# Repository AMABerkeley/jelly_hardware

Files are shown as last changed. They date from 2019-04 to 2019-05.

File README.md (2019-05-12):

# jelly_hardware
Hardware for Jelly Robot

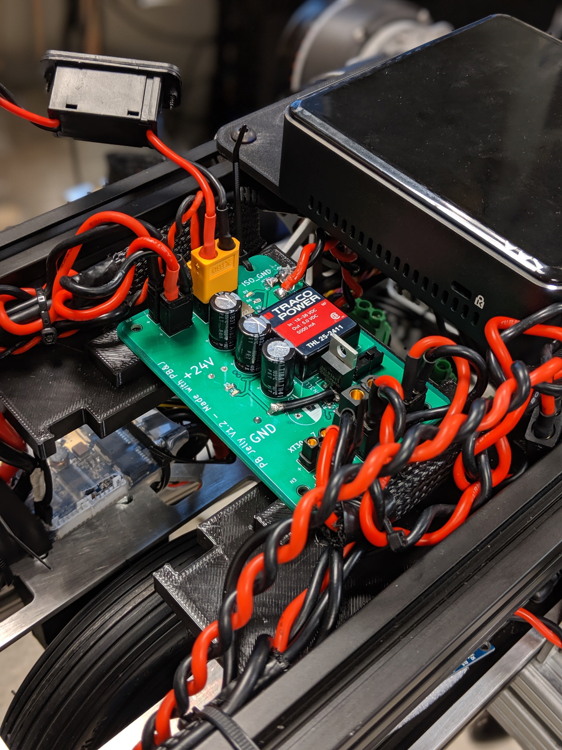
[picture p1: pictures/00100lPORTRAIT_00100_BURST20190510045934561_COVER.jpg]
3dview


More to come...

Useful for protecting against sparks and having an isolated ground for a computer.

Input Voltage is 24V from this device: [Kobalt](https://www.lowes.com/pd/Kobalt-24-Volt-1-5-Amp-Hours-Lithium-Power-Tool-Battery/1000090833)

Output Voltage at XT30 and XT60 is 24V

Output Voltage at Isolated pins: 5V 5A

V1.0 has been sent out.

TODO V2.0: Add PMOS to 24V to prevent damage to circuit if battery connected wrong way. Add connector for computer power. Add LED indicators.

Components:

DCDC Isolated 5V5A
https://www.digikey.com/product-detail/en/traco-power/THL-25-2411/1951-1620-ND/9382657
https://www.tracopower.com/products/thl25.pdf
https://assets.tracopower.com/20190412132953/THL25/documents/thl25-application.pdf

Inductor
https://www.mouser.com/ProductDetail/Coilcraft/XEL6060-222MEB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

NMOS
current nmos https://www.digikey.com/product-detail/en/stmicroelectronics/STP160N3LL/497-16021-5-ND/5455754
backup NMOS https://www.digikey.com/product-detail/en/infineon-technologies/IRLB3813PBF/IRLB3813PBF-ND/2118485

Batttery Terminal Connector
https://www.digikey.com/product-detail/en/te-connectivity-amp-connectors/1-725996-2/A130982-ND/2055902
Specs https://www.te.com/commerce/DocumentDelivery/DDEController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

Inspiration: https://easyeda.com/editor#id=83191bc7c7a1436bab31f7c8314d08c5|0a66ceef99064df6ad66a18129efbc26

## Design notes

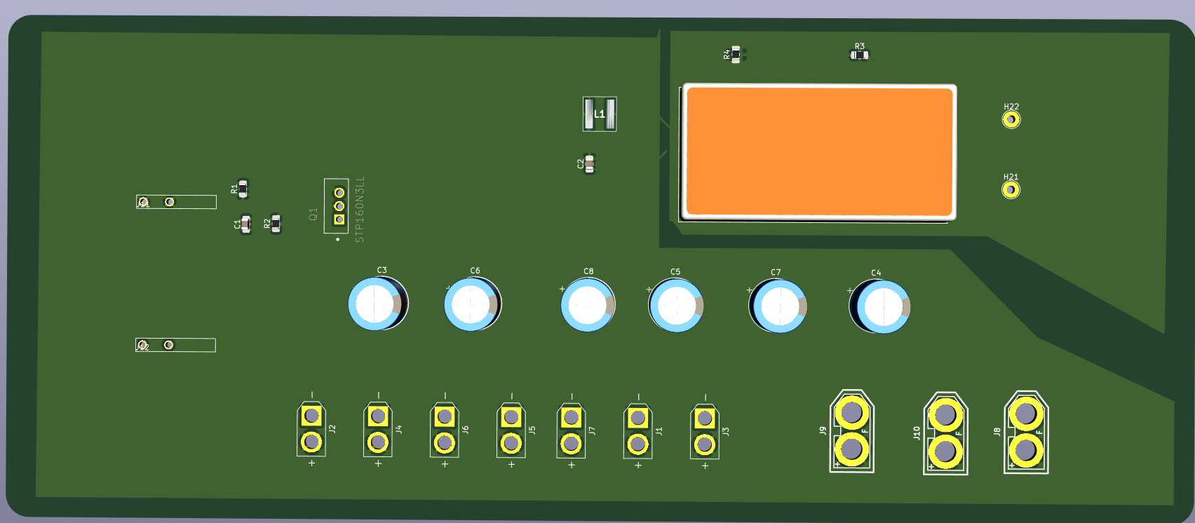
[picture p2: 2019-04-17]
pictures/3dview.png

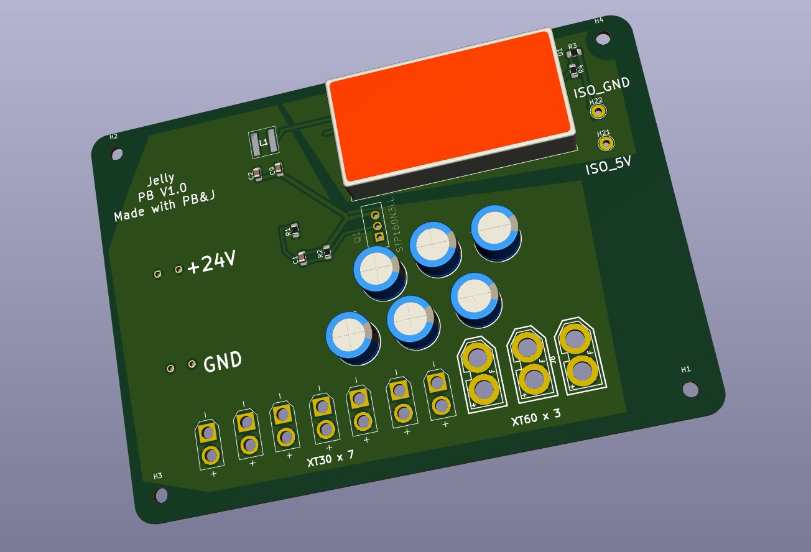
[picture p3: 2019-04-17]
pictures/05C11D99-9A95-4C3E-8D60-CFA752C3F91C.jpeg

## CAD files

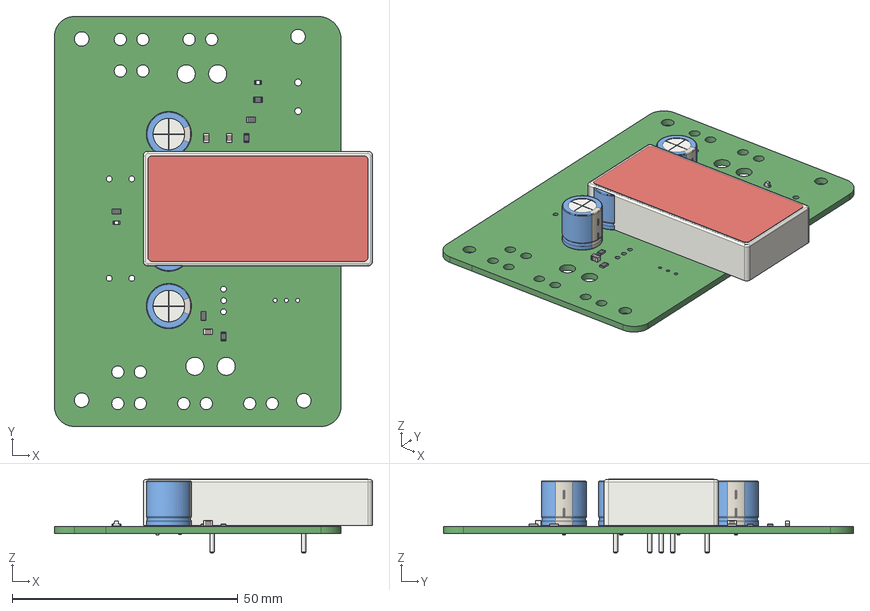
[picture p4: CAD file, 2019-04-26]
power board.step
70.5 x 90.8 x 16.3 mm

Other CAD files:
kicad-footprints-master/Sources/Inductor_SMD/L_Coilcraft_LPS5030.FCStd
kicad-footprints-master/Sources/Package_SON/X2SON-4_1x1mm_P0.65mm.fcstd
kicad-footprints-master/Sources/Package_TO_SOT_THT/sod-70_P5.08mm.fcstd
kicad-footprints-master/Sources/Package_TO_SOT_THT/sod-70.fcstd

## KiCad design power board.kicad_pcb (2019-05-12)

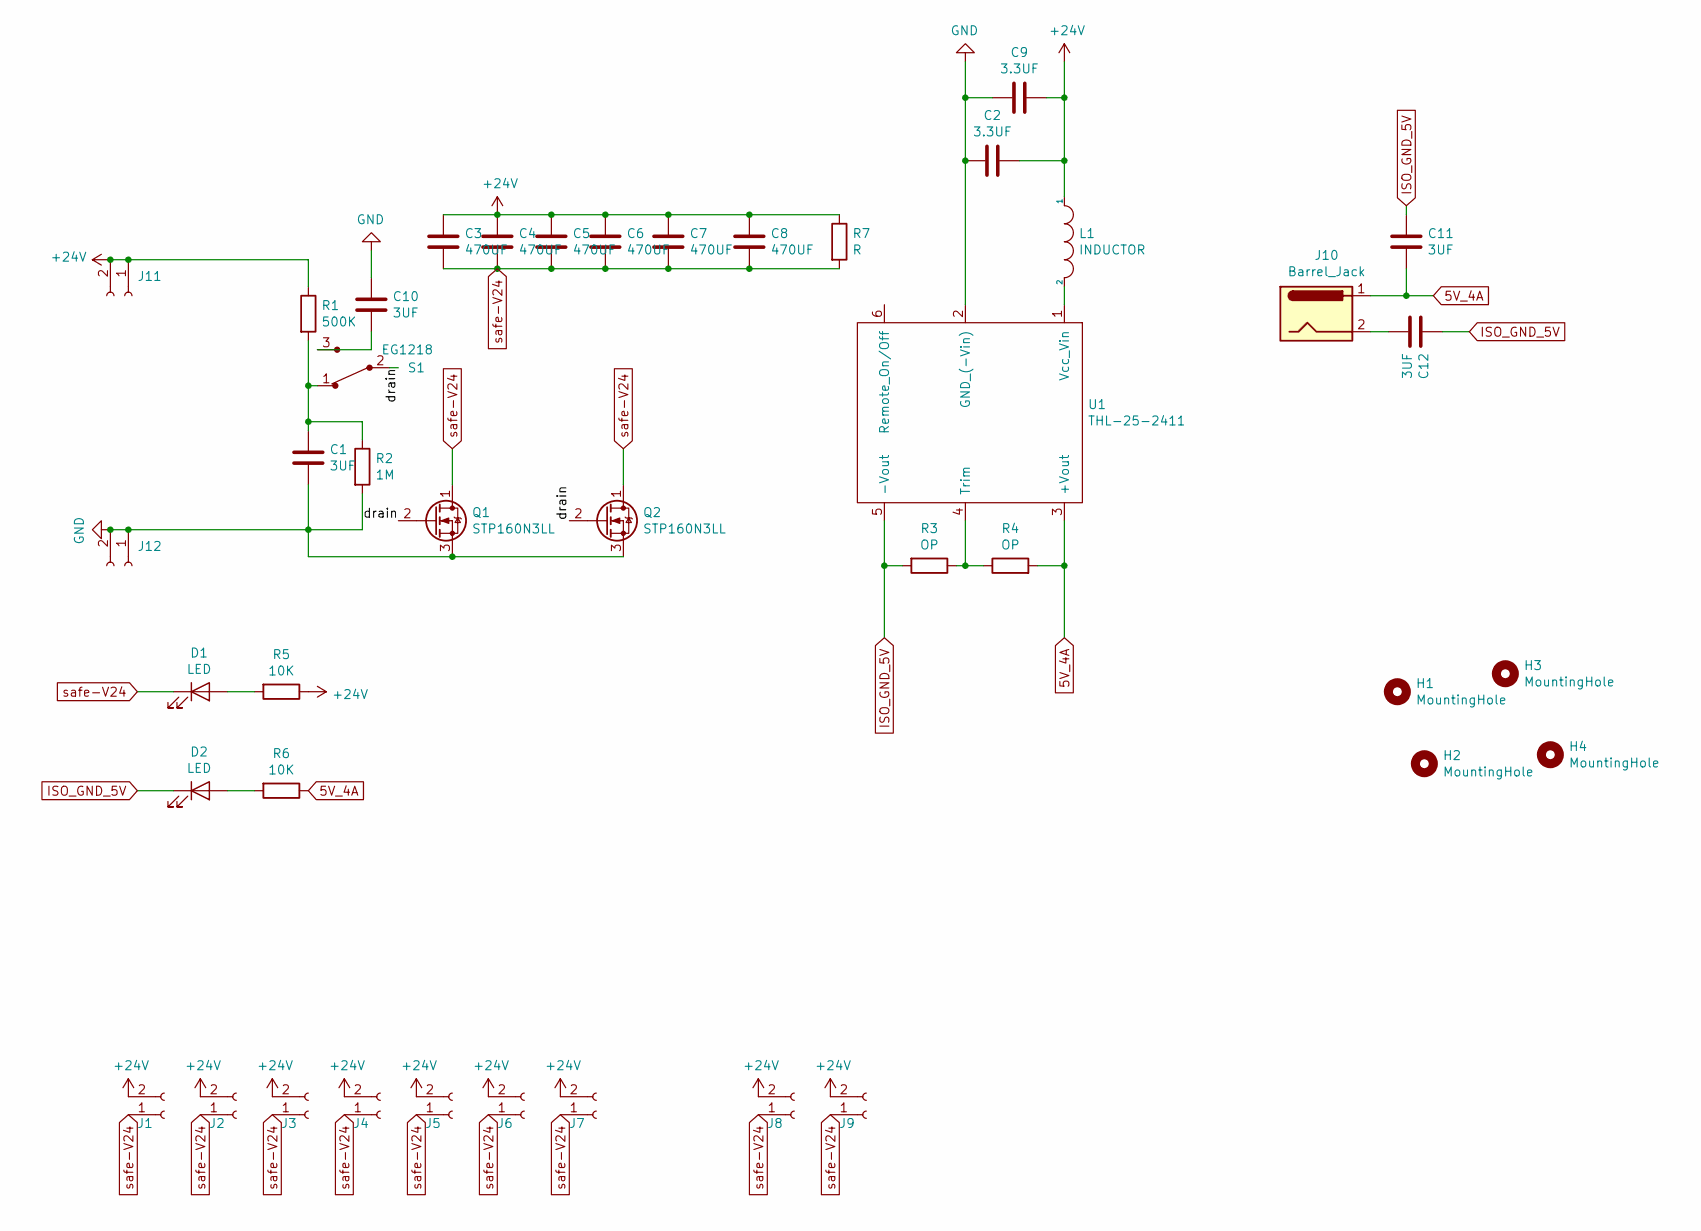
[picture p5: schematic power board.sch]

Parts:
C1, C10, C11, C12: 3UF; C_0805_2012Metric_Pad1.15x1.40mm_HandSolder
C2, C9: 3.3UF; C_0805_2012Metric_Pad1.15x1.40mm_HandSolder
C3, C4, C5, C6, C7, C8: 470UF; CP_Radial_D10.0mm_P5.00mm
D1, D2: LED; LED_0603_1608Metric_Pad1.05x0.95mm_HandSolder
H1, H2, H3, H4: MountingHole; MountingHole_3.2mm_M3_Pad_Via
J1, J2, J3, J4, J5, J6, J7: Conn_01x02_Female; AMASS_XT30U-F_1x02_P5.0mm_Vertical
J8, J9: Conn_01x02_Female; XT-60_female
J10: Barrel_Jack; BarrelJack_CUI_PJ-063AH_Horizontal
J11, J12: Conn_01x02_Female; battery_conector_powerpack
L1: INDUCTOR; XEL6060-152MEC
Q1, Q2: STP160N3LL; MOSFET_Down
R1: 500K; R_0805_2012Metric_Pad1.15x1.40mm_HandSolder
R2: 1M; R_0805_2012Metric_Pad1.15x1.40mm_HandSolder
R3, R4: OP; R_0805_2012Metric_Pad1.15x1.40mm_HandSolder
R5, R6: 10K; R_0805_2012Metric_Pad1.15x1.40mm_HandSolder
R7: R; R_0805_2012Metric_Pad1.15x1.40mm_HandSolder
S1: EG1218; Switch_Slide_11.6x4mm_EG1218; MPN EG1218; Digi-Key_PN EG1903-ND
U1: THL-25-2411; Converter_DCDC_TRACO_TEN20-xxxx_THT-modified

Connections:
5V_4A: C11.2, J10.1, R4.2, R6.1, U1.3 (+Vout)
+24V: C2.2, C3.1, C4.1, C5.1, C6.1, C7.1, C8.1, C9.2, J1.2, J2.2, J3.2, J4.2, J5.2, J6.2, J7.2, J8.2, J9.2, J11.1, J11.2, L1.1, R1.1, R5.1, R7.1
/drain: Q1.2 (G), Q2.2 (G), S1.2
GND: C1.2, C2.1, C9.1, C10.1, J12.1, J12.2, Q1.3 (S), Q2.3 (S), R2.2, U1.2 (GND_(-Vin))
ISO_GND_5V: C11.1, C12.1, D2.1 (K), R3.2, U1.5 (-Vout)
unnamed: C1.1, R1.2, R2.1, S1.1
unnamed: C10.2, S1.3
unnamed: C12.2, J10.2
unnamed: D1.2 (A), R5.2
unnamed: D2.2 (A), R6.2
unnamed: L1.2, U1.1 (Vcc_Vin)
unnamed: R3.1, R4.1, U1.4 (Trim)
safe-V24: C3.2, C4.2, C5.2, C6.2, C7.2, C8.2, D1.1 (K), J1.1, J2.1, J3.1, J4.1, J5.1, J6.1, J7.1, J8.1, J9.1, Q1.1 (D), Q2.1 (D), R7.2

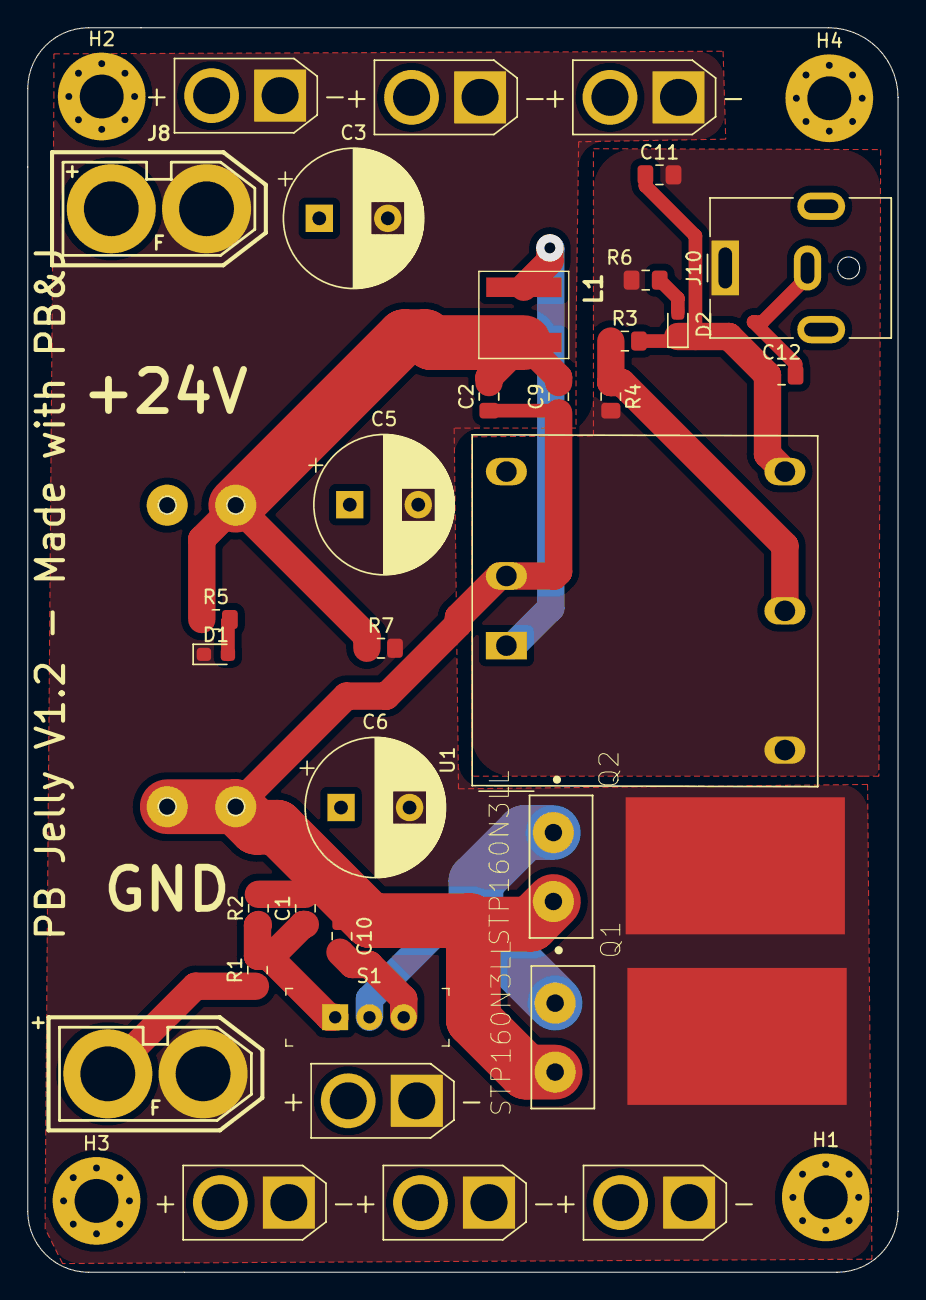
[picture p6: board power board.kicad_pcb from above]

Board: 2 copper layers, 63.5 x 90.8 mm, 39 parts (0 on the bottom side), 13 nets.

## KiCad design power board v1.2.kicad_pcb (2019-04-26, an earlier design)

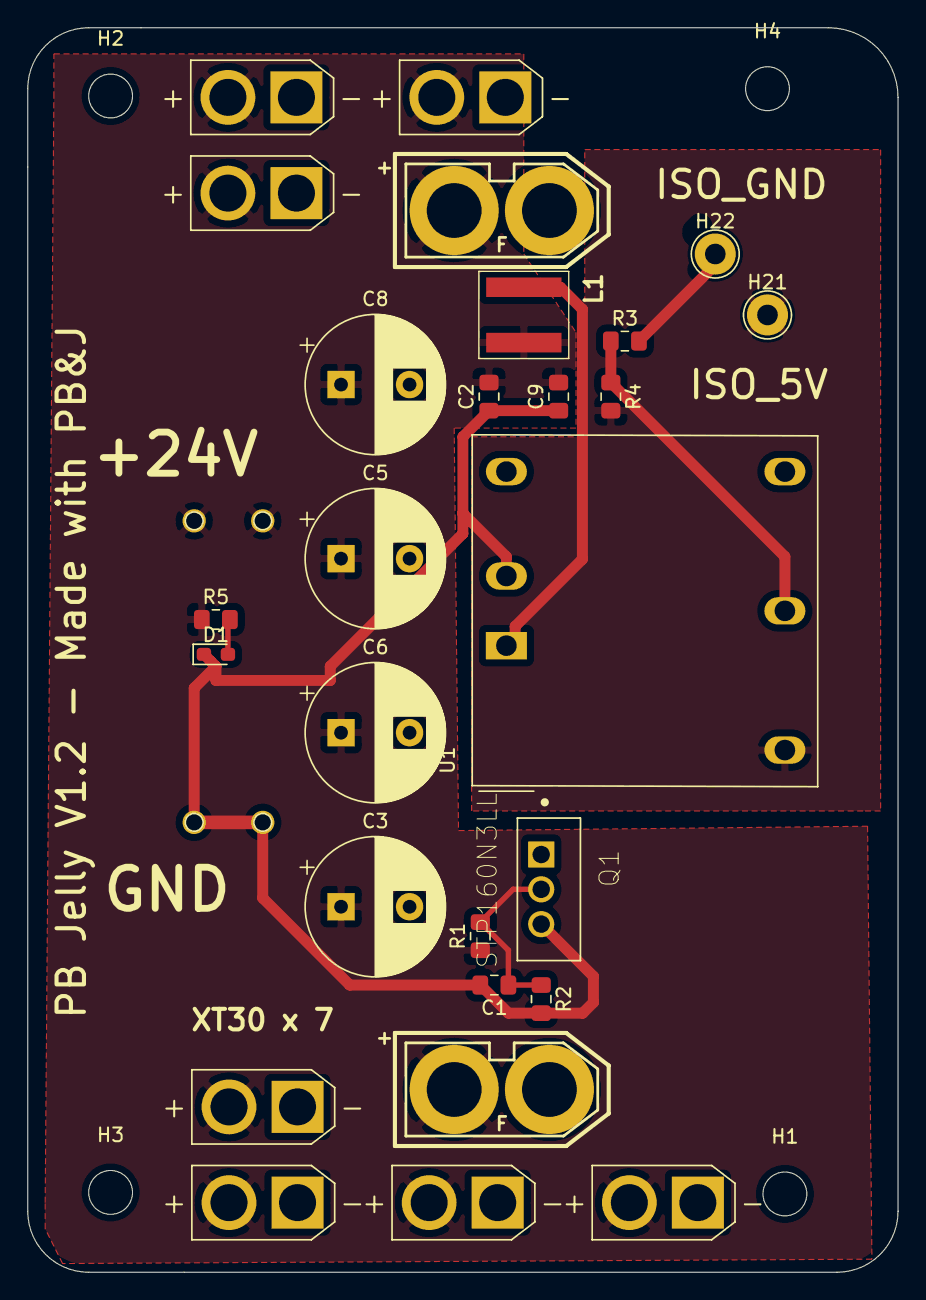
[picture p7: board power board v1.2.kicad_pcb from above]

Board: 2 copper layers, 63.5 x 90.8 mm, 33 parts (0 on the bottom side), 9 nets.

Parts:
C1: .1UF; C_0805_2012Metric_Pad1.15x1.40mm_HandSolder
C2, C9: 3.3UF; C_0805_2012Metric_Pad1.15x1.40mm_HandSolder
C3, C5, C6, C8: 470UF; CP_Radial_D10.0mm_P5.00mm
D1: LED; LED_0603_1608Metric_Pad1.05x0.95mm_HandSolder
H1, H2, H3, H4: MountingHole; MountingHole_3.2mm_M3
H21, H22: MountingHole_Pad; TestPoint_THTPad_D3.0mm_Drill1.5mm
J1, J2, J3, J4, J5, J6, J7: Conn_01x02_Female; AMASS_XT30U-F_1x02_P5.0mm_Vertical
J9, J10: Conn_01x02_Female; XT-60_female
J11, J12: Conn_01x02_Female; battery_conector_powerpack
L1: INDUCTOR; XEL6060-152MEC
Q1: STP160N3LL; TO254P1040X460X1935-3
R1, R2: 1K; R_0805_2012Metric_Pad1.15x1.40mm_HandSolder
R3, R4: OP; R_0805_2012Metric_Pad1.15x1.40mm_HandSolder
R5: 10K; R_0805_2012Metric_Pad1.15x1.40mm_HandSolder
U1: THL-25-2411; Converter_DCDC_TRACO_TEN20-xxxx_THT-modified

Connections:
5V_4A: H21.1, R4.2, U1.3
+24V: C2.2, C3.1, C5.1, C6.1, C8.1, C9.2, J1.2, J2.2, J3.2, J4.2, J5.2, J6.2, J7.2, J9.2, J10.2, J11.1, J11.2, L1.1, R1.1, R5.1
GND: C1.2, C2.1, C9.1, D1.1, J12.1, J12.2, Q1.3, R2.2, U1.2
ISO_GND_5V: H22.1, R3.2, U1.5
unnamed: C1.1, Q1.2, R1.2, R2.1
unnamed: D1.2, R5.2
unnamed: L1.2, U1.1
unnamed: R3.1, R4.1, U1.4
safe-V24: C3.2, C5.2, C6.2, C8.2, J1.1, J2.1, J3.1, J4.1, J5.1, J6.1, J7.1, J9.1, J10.1, Q1.1

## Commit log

2019-04-17 created initial v0.0 of board
    [power board.kicad_pcb, power board.sch]
2019-04-17 deleted diode and added caps
    [power board.kicad_pcb, power board.sch]
2019-04-17 final V1.0 sent out -gerbers zipped
    [power board.kicad_pcb, power board.sch]
2019-04-18 need to add LED's
2019-04-26 added leds annd switch and decreased size
    [power board v1.2.kicad_pcb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]
2019-04-29 added some nicer features
    [power board-B_Cu.gbr, power board-B_Mask.gbr, power board-B_Paste.gbr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]
2019-05-12 updated board to v1.2
    [L_Coilcraft_LPS5030.FCStd, TREX_board.kicad_pcb, TREX_board.sch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]
